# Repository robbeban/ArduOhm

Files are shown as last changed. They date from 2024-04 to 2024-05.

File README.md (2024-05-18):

# ArduOhm
Roberto De Colle ver. 0.2
22.4.2024

Ohmmeter with automatic scale with Arduino

Use a voltage divider with known R1 and unknown Rx as in the picture.

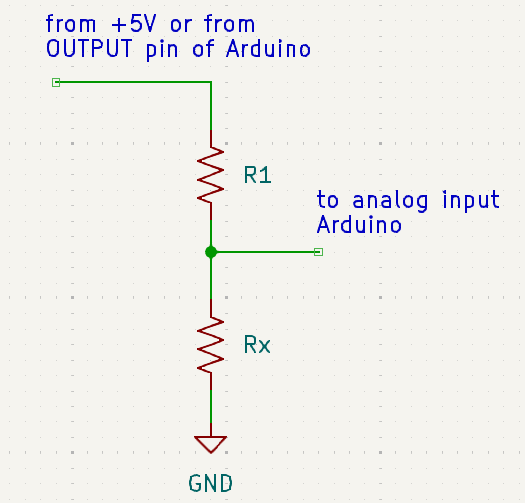
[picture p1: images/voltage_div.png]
<br>
Voltage on Rx is read from AnalogRead(A0) and converted in volt.

## Problem
With a fix R1 value (as 1K), the Rx value can be not accurate enough if Rx << R1 or Rx >> R1.
Therefore we need to change measurement scale changing the R1 value to be more similar to Rx value.<br>
## Solution
This can be made using 5 different R1 values and therefore 5 different measurement scale.

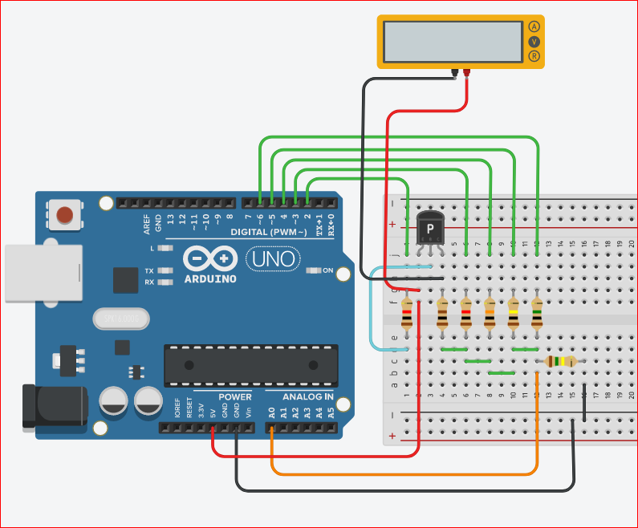
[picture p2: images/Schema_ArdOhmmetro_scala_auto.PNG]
<br>

In pic you see 5 different "R1" resistor, 100, 1K, 10K, 100K, 1M.
5 Output pins of Arduino put 5V on the right R1, but just one output at a time can be on +5V otherwise all R1 will be 
in parallel as one resistor.
This is achieved setting all output pin as input pin (equivalent R is great and therefore no resistor is connected to 5V) and then just one pin at a time is setted as output e brought to +5V.
This make an automatic scale to use the suitable value for R1.
## Another problem
By measuring little values of Rx, the right scale has a R1 = 100; with little value of R1+Rx the current provided from Arduino is too high (ca. 50 mA or more).
Therefore we use a PNP transistor to request just a few little current from pin.
In order of turning on the PNP transistor, we need to set output pin LOW instead of HIGH as for the other scales.

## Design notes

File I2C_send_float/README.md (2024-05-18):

# Prova per trasmettere dati float tra due Arduino collegati via I2C

Schema di collegamento<br>
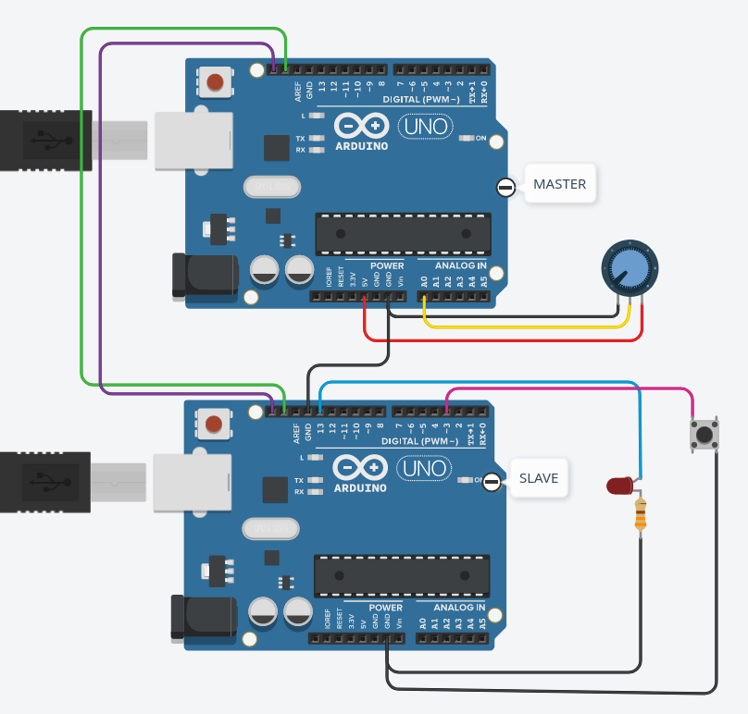
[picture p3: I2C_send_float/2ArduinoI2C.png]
<br>

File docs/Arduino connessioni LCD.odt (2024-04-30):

Connessione DISPLAYTECH 162B

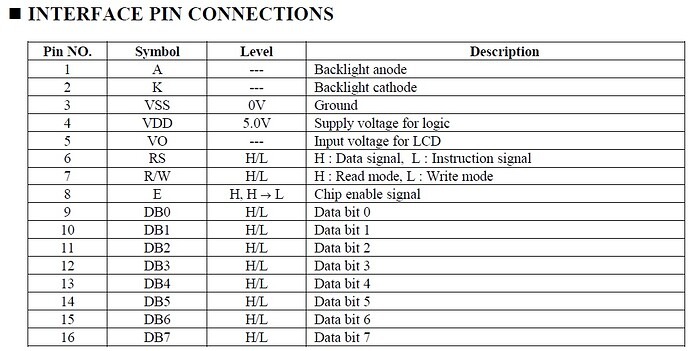
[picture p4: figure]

MANCA SCHEMA DI MONTAGGIO!!!!!!

Connessione DISPLAY 1602A

Pin. N. | Simbolo | Descrizione
1 | VSS | collegamento a terra
2 | VDD | alimentazione 5 volt
3 | V0 | regolazione del contrasto
4 | RS | register select: High=dati, Low=istruzioni
5 | R/W | High=Read; Low=Write
6 | E | Abilita (High) o disabilita (Low) l’ingresso di un byte
7 | D0 | data bus - bit 0
8 | D1 | data bus - bit 1
9 | D2 | data bus - bit 2
10 | D3 | data bus - bit 3
11 | D4 | data bus - bit 4
12 | D5 | data bus - bit 5
13 | D6 | data bus - bit 6
14 | D7 | data bus - bit 7
15 | BL-A | retroilluminazione (5 volt)
16 | BL-K | retroilluminazione (gnd)

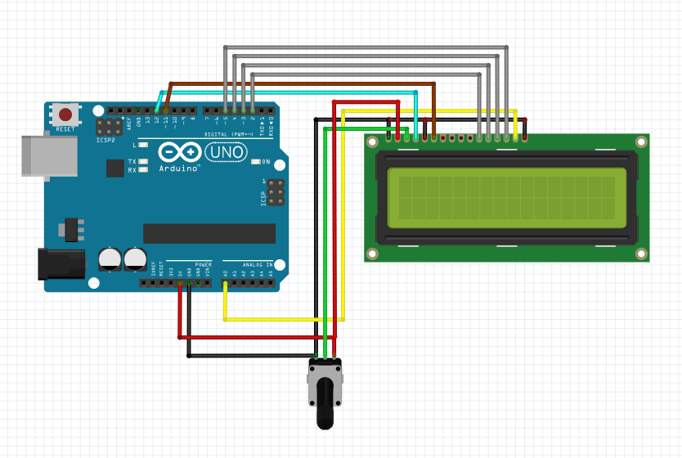
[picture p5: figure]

PIN ARDUINO | PIN LCD | | Pin ARDUINO alternativi
12 | RS | 4
11 | E | 6
5 | D7 | 14 | 10
4 | D6 | 13 | 9
3 | D5 | 12 | 8
2 | D4 | 11 | 7
GND | VSS | 1
+5V | VDD | 2
GND | R/W | 5
ALTRI PIN
POT1 | +5V
POT2 | V0 | 3
POT3 | GND
retro- | +5V | 15
iluminazione | GND | 16

Il display riceve, memorizza in un registro e visualizza il byte seguendo le istruzioni che gli vengono fornite attraverso i pin 4, 5 e 6. Piu’ in dettaglio:

- I pin da 1 a 3 sono utilizzati per alimentare il display e per regolare (mediante un potenziometro) il contrasto dei caratteri
- Il pin 4 (register select) è un selettore che, se dichiarato High predispone il registro del display a ricevere un byte mentre se dichiarato Low tiene il registro in attesa del prossimo evento.
- Il pin 5 stabilisce la modalità di utilizzo del registro. Se è LOW il registro è in ricezione (write) mentre se è HIGH il registro rende disponibile l’immagine del byte appena memorizzato. Se non si ha necessità di interrogare il byte presente nel registro conviene mantenere questo pin costantemente LOW e quindi collegato a terra.
- Il pin 6 abilita o disabilita l’ingresso e la visualizzazione del byte
- I pin da 7 a 14 rappresentano, come detto, la configurazione del byte da visualizzare
- I pin 15 e 16 sono utilizzati per illuminare il fondo del display. Devono essere collegati all’alimentazione da 5 volt ed alla massa o, eventualmente, ad un interruttore. Attenzione che a bordo scheda deve esserci la resistenza R8 (circa 100-330 ohm) per limitare la corrente. Possono anche ovviamente essere collegate ad una porta di Arduino e pilotate da programma (es. da una routine tipo luce crepuscolare).

Il display può lavorare in modalità 8 bit oppure in modalità 4 bit; se lavora in modalità 8 bit può visualizzare tutto il set di caratteri ascii (maiuscole, minuscole e caratteri speciali), ma richiede l’utilizzo di 10 porte mentre se lavora in modalità 4 bit utilizza solo 6 porte (4 per i dati, una per il selettore ed una per abilitare disabilitare la visualizzazione). Per mostrare un testo formato da numeri, caratteri maiuscoli o minuscoli e punteggiatura è sufficiente utilizzare la modalità a 4 bit.

Per provare tutte le funzionalità “fisiche” del display aggiungeremo anche un potenziometro collegato al pin 3 in modo da poter regolare il contrasto.

Verificare di poter collegare una semplice R da 330 ohm tra V0 e GND per regolare il contrasto!

E se si può collegare una semplice R da 6,8 Kohm tra pin 15 e +5V !!

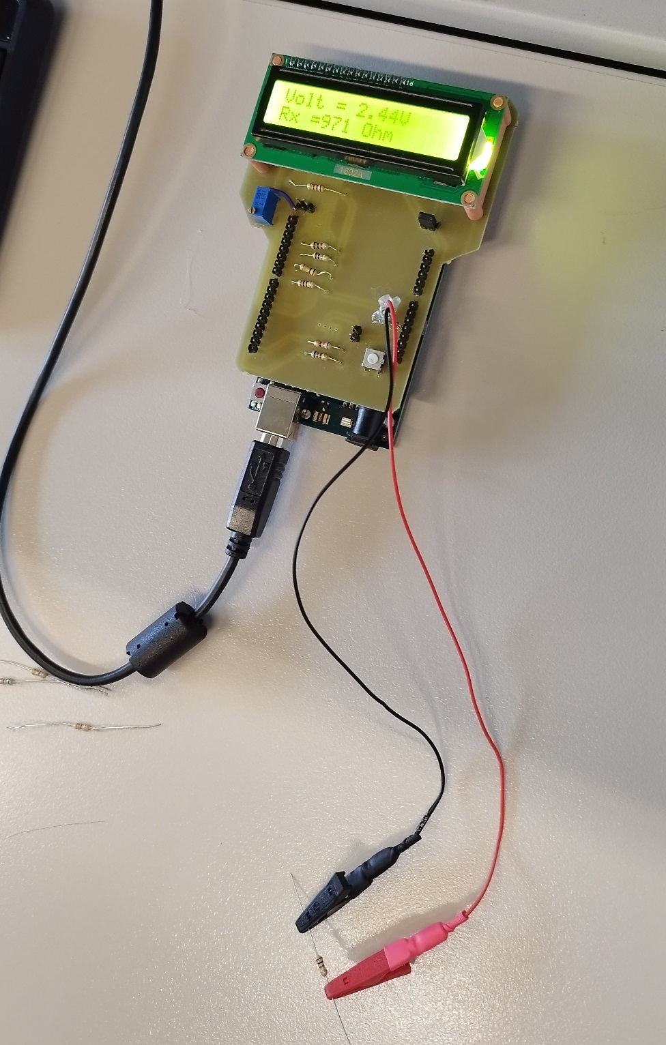
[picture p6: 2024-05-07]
images/Arduohmmetro2.jpg

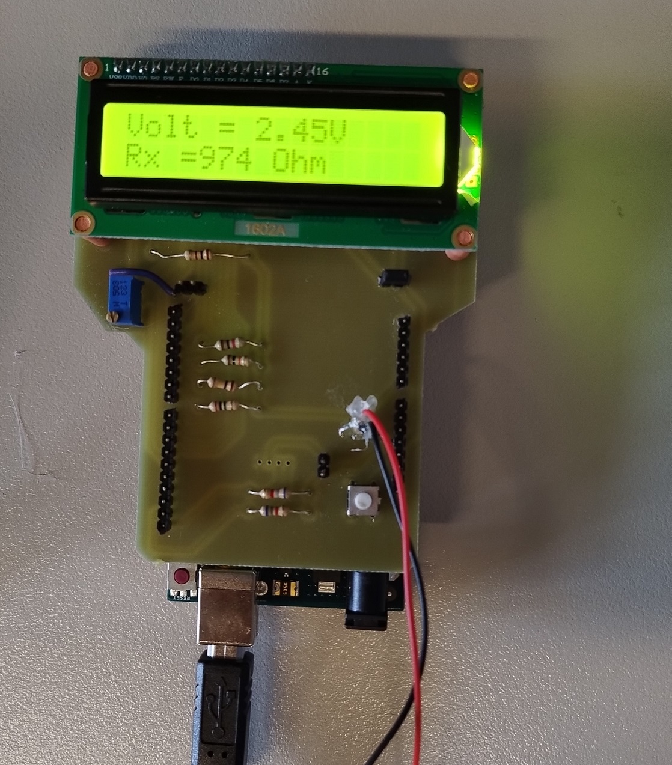
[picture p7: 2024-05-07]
images/Arduohmmetro1.jpg

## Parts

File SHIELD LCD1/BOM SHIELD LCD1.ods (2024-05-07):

H:\Documents\Documenti_scuola\Documenti_2023-2024\Didattica\2EL\KICAD\SHIELD LCD1\SHIELD LCD1.kicad_sch
02/05/2024 10:40:01
Eeschema 7.0.7
C:\Program Files\KiCad\7.0\bin\scripting\plugins/bom_csv_grouped_by_value.py
26
LISTA MATERIALI BOM
Qty | Reference(s) | Value | LibPart | Footprint
2 | J1, J4 | Conn_01x08 | Connector_Generic:Conn_01x08 | Connector_PinHeader_2.54mm:PinHeader_1x08_P2.54mm_Vertical
1 | J2 | Conn_01x10 | Connector_Generic:Conn_01x10 | Connector_PinHeader_2.54mm:PinHeader_1x10_P2.54mm_Vertical
1 | J3 | Conn_01x06 | Connector_Generic:Conn_01x06 | Connector_PinHeader_2.54mm:PinHeader_1x06_P2.54mm_Vertical
1 | J5 | RX | Connector_Generic:Conn_01x02 | Connector_PinHeader_2.54mm:PinHeader_1x02_P2.54mm_Vertical
1 | J6 | Conn_01x16 | Connector_Generic:Conn_01x16 | Connector_PinHeader_2.54mm:PinHeader_1x16_P2.54mm_Vertical
1 | J7 | Con2 | Connector_Generic:Conn_01x02 | Connector_PinHeader_2.54mm:PinHeader_1x02_P2.54mm_Vertical
1 | J8 | I2C | Connector_Generic:Conn_01x04 | Connector:NS-Tech_Grove_1x04_P2mm_Vertical
1 | JP1 | J5V | Jumper:Jumper_2_Open | TestPoint:TestPoint_2Pads_Pitch2.54mm_Drill0.8mm
1 | JP2 | BACKLIGHT | Jumper:Jumper_2_Open | TestPoint:TestPoint_2Pads_Pitch2.54mm_Drill0.8mm
1 | Q1 | BC556 | Transistor_BJT:BC556 | Package_TO_SOT_THT:TO-92_Inline_Wide
2 | R1, R3 | 1K | Device:R | Resistor_THT:R_Axial_DIN0309_L9.0mm_D3.2mm_P12.70mm_Horizontal
1 | R2 | 100 | Device:R | Resistor_THT:R_Axial_DIN0411_L9.9mm_D3.6mm_P20.32mm_Horizontal
1 | R4 | 10K | Device:R | Resistor_THT:R_Axial_DIN0309_L9.0mm_D3.2mm_P12.70mm_Horizontal
1 | R5 | 100K | Device:R | Resistor_THT:R_Axial_DIN0309_L9.0mm_D3.2mm_P12.70mm_Horizontal
1 | R6 | 1M | Device:R | Resistor_THT:R_Axial_DIN0309_L9.0mm_D3.2mm_P12.70mm_Horizontal
2 | R7, R8 | 6K8 | Device:R | Resistor_THT:R_Axial_DIN0309_L9.0mm_D3.2mm_P12.70mm_Horizontal
1 | RV1 | 50K | Device:R_Potentiometer_Trim | Potentiometer_THT:Potentiometer_Bourns_3296X_Horizontal
1 | SW1 | RESET | Switch:SW_MEC_5E | 00_MATTEI:SW_PUSH_6mm_H4.3mm

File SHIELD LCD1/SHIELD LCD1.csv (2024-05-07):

Source: | H:\Documents\Documenti_scuola\Documenti_2023-2024\Didattica\2EL\KICAD\SHIELD LCD1\SHIELD LCD1.kicad_sch
Date: | 02/05/2024 10:40:01
Tool: | Eeschema 7.0.7
Generator: | C:\Program Files\KiCad\7.0\bin\scripting\plugins/bom_csv_grouped_by_value.py
Component Count: | 26
Collated Components:
Item | Qty | Reference(s) | Value | LibPart | Footprint | Datasheet | DNP
1 | 1 | DS1 | WC1602A | Display_Character:WC1602A | Display:WC1602A | http://www.wincomlcd.com/pdf/WC1602A-SFYLYHTC06.pdf
2 | 4 | H1, H2, H3, H4 | MountingHole | Mechanical:MountingHole | MountingHole:MountingHole_2.5mm | ~
3 | 2 | J1, J4 | Conn_01x08 | Connector_Generic:Conn_01x08 | Connector_PinHeader_2.54mm:PinHeader_1x08_P2.54mm_Vertical | ~
4 | 1 | J2 | Conn_01x10 | Connector_Generic:Conn_01x10 | Connector_PinHeader_2.54mm:PinHeader_1x10_P2.54mm_Vertical | ~
5 | 1 | J3 | Conn_01x06 | Connector_Generic:Conn_01x06 | Connector_PinHeader_2.54mm:PinHeader_1x06_P2.54mm_Vertical | ~
6 | 1 | J5 | RX | Connector_Generic:Conn_01x02 | Connector_PinHeader_2.54mm:PinHeader_1x02_P2.54mm_Vertical | ~
7 | 1 | J6 | Conn_01x16 | Connector_Generic:Conn_01x16 | Connector_PinHeader_2.54mm:PinHeader_1x16_P2.54mm_Vertical | ~
8 | 1 | J7 | Con2 | Connector_Generic:Conn_01x02 | Connector_PinHeader_2.54mm:PinHeader_1x02_P2.54mm_Vertical | ~
9 | 1 | J8 | I2C | Connector_Generic:Conn_01x04 | Connector:NS-Tech_Grove_1x04_P2mm_Vertical | ~
10 | 1 | JP1 | J5V | Jumper:Jumper_2_Open | TestPoint:TestPoint_2Pads_Pitch2.54mm_Drill0.8mm | ~
11 | 1 | JP2 | BACKLIGHT | Jumper:Jumper_2_Open | TestPoint:TestPoint_2Pads_Pitch2.54mm_Drill0.8mm | ~
12 | 1 | Q1 | BC556 | Transistor_BJT:BC556 | Package_TO_SOT_THT:TO-92_Inline_Wide | https://www.onsemi.com/pub/Collateral/BC556BTA-D.pdf
13 | 2 | R1, R3 | 1K | Device:R | Resistor_THT:R_Axial_DIN0309_L9.0mm_D3.2mm_P12.70mm_Horizontal | ~
14 | 1 | R2 | 100 | Device:R | Resistor_THT:R_Axial_DIN0411_L9.9mm_D3.6mm_P20.32mm_Horizontal | ~
15 | 1 | R4 | 10K | Device:R | Resistor_THT:R_Axial_DIN0309_L9.0mm_D3.2mm_P12.70mm_Horizontal | ~
16 | 1 | R5 | 100K | Device:R | Resistor_THT:R_Axial_DIN0309_L9.0mm_D3.2mm_P12.70mm_Horizontal | ~
17 | 1 | R6 | 1M | Device:R | Resistor_THT:R_Axial_DIN0309_L9.0mm_D3.2mm_P12.70mm_Horizontal | ~
18 | 2 | R7, R8 | 6K8 | Device:R | Resistor_THT:R_Axial_DIN0309_L9.0mm_D3.2mm_P12.70mm_Horizontal | ~
19 | 1 | RV1 | 50K | Device:R_Potentiometer_Trim | Potentiometer_THT:Potentiometer_Bourns_3296X_Horizontal | ~
20 | 1 | SW1 | RESET | Switch:SW_MEC_5E | 00_MATTEI:SW_PUSH_6mm_H4.3mm | http://www.apem.com/int/index.php?controller=attachment&id_attachment=1371

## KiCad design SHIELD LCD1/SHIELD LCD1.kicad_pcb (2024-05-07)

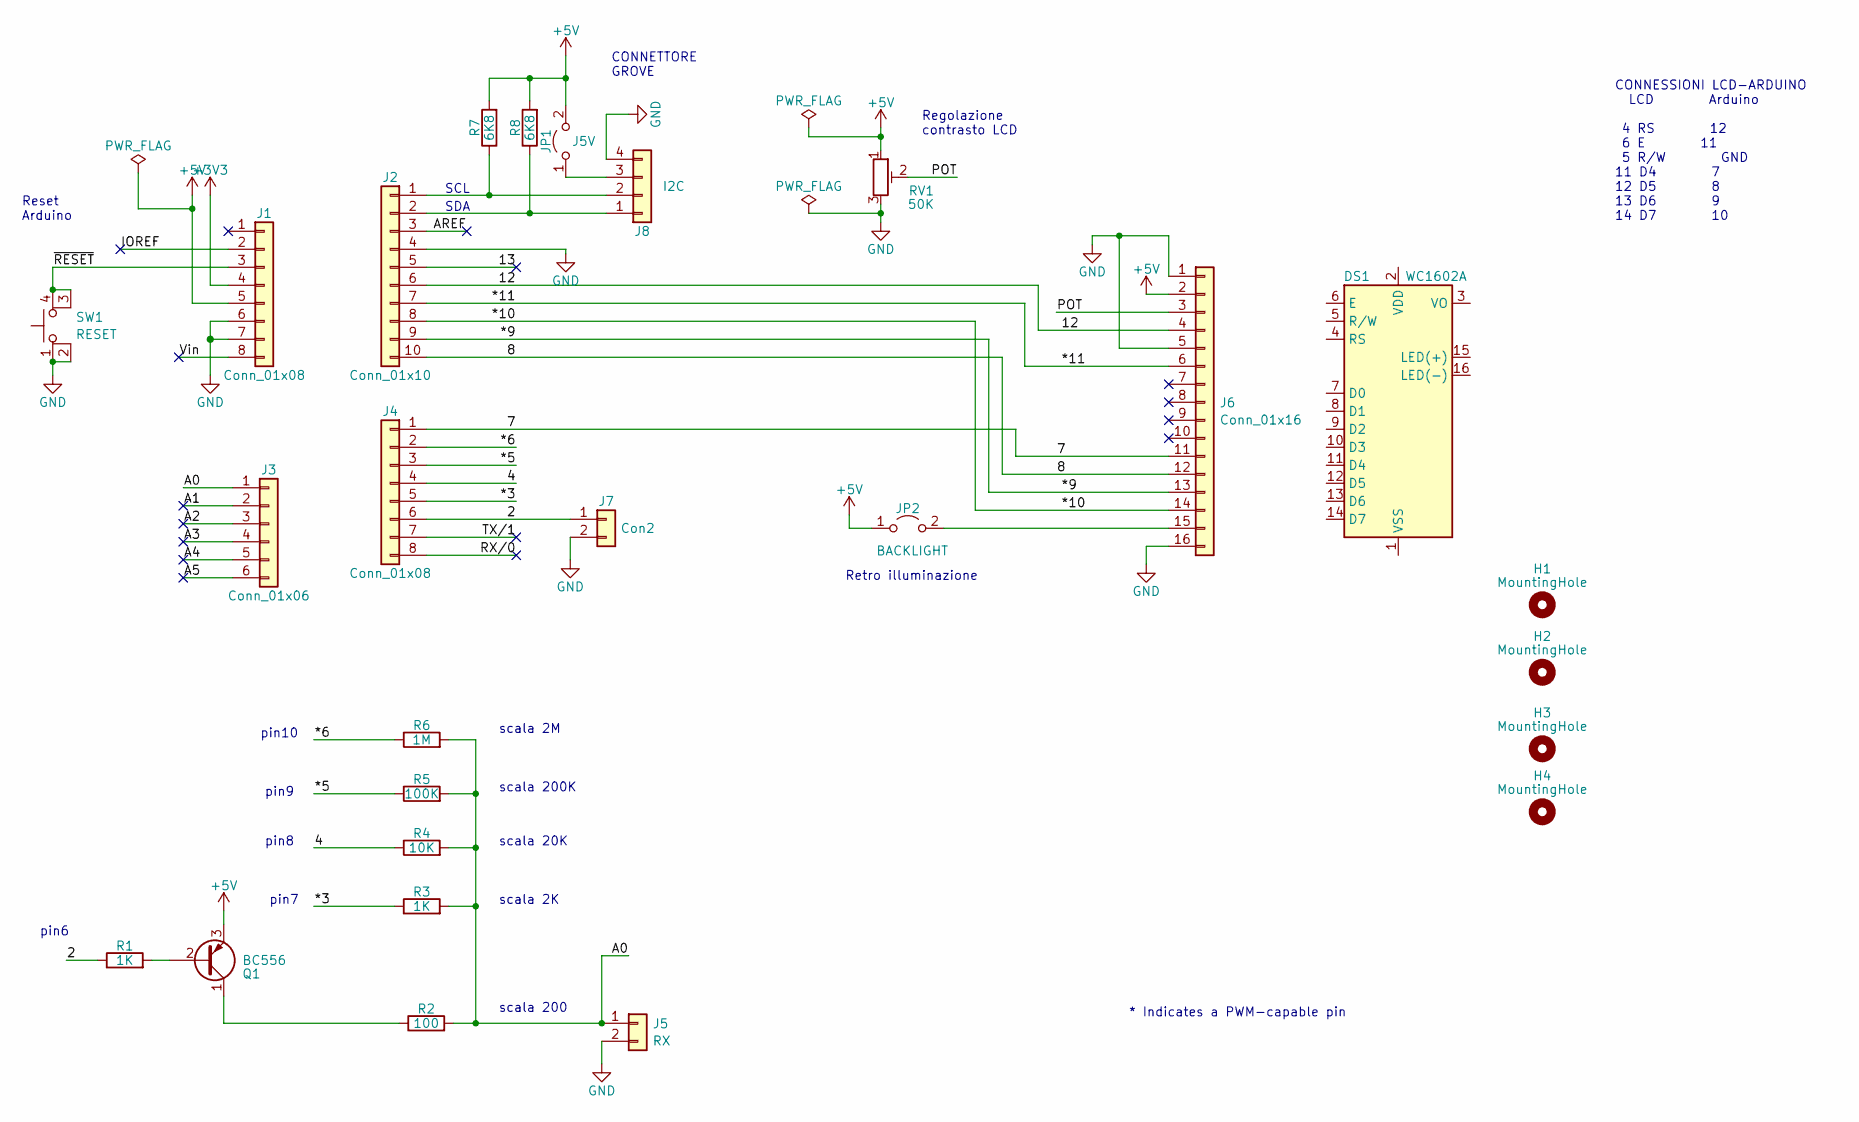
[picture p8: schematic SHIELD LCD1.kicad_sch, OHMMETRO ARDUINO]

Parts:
DS1: WC1602A
H1, H2, H3, H4: MountingHole; MountingHole_2.5mm
J1, J4: Conn_01x08; PinHeader_1x08_P2.54mm_Vertical
J2: Conn_01x10; PinHeader_1x10_P2.54mm_Vertical
J3: Conn_01x06; PinHeader_1x06_P2.54mm_Vertical
J5: RX; PinHeader_1x02_P2.54mm_Vertical
J6: Conn_01x16; PinHeader_1x16_P2.54mm_Vertical
J7: Con2; PinHeader_1x02_P2.54mm_Vertical
J8: I2C; NS-Tech_Grove_1x04_P2mm_Vertical
JP1: J5V; TestPoint_2Pads_Pitch2.54mm_Drill0.8mm
JP2: BACKLIGHT; TestPoint_2Pads_Pitch2.54mm_Drill0.8mm
Q1: BC556; TO-92_Inline_Wide
R1, R3: 1K; R_Axial_DIN0309_L9.0mm_D3.2mm_P12.70mm_Horizontal
R2: 100; R_Axial_DIN0411_L9.9mm_D3.6mm_P20.32mm_Horizontal
R4: 10K; R_Axial_DIN0309_L9.0mm_D3.2mm_P12.70mm_Horizontal
R5: 100K; R_Axial_DIN0309_L9.0mm_D3.2mm_P12.70mm_Horizontal
R6: 1M; R_Axial_DIN0309_L9.0mm_D3.2mm_P12.70mm_Horizontal
R7, R8: 6K8; R_Axial_DIN0309_L9.0mm_D3.2mm_P12.70mm_Horizontal
RV1: 50K; Potentiometer_Bourns_3296X_Horizontal
SW1: RESET; SW_PUSH_6mm_H4.3mm

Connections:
+3V3: J1.4
+5V: J1.5, J6.2, JP1.2 (B), JP2.1 (A), Q1.3 (E), R7.2, R8.2, RV1.1
/2: J4.6, J7.1, R1.1
/4: J4.4, R4.1
/7: J4.1, J6.11
/8: J2.10, J6.12
/12: J2.6, J6.4
/13: J2.5
/*3: J4.5, R3.1
/*5: J4.3, R5.1
/*6: J4.2, R6.1
/*9: J2.9, J6.13
/*10: J2.8, J6.14
/*11: J2.7, J6.6
/A0: J3.1, J5.1, R2.2, R3.2, R4.2, R5.2, R6.2
/A1: J3.2
/A2: J3.3
/A3: J3.4
/A4: J3.5
/A5: J3.6
/AREF: J2.3
/IOREF: J1.2
/POT: J6.3, RV1.2
/RX/0: J4.8
/TX/1: J4.7
/Vin: J1.8
/~RESET: J1.3, SW1.3 (K), SW1.4 (A)
GND: J1.6, J1.7, J2.4, J5.2, J6.1, J6.5, J6.16, J7.2, J8.4, RV1.3, SW1.1, SW1.2
unnamed: J2.1, J8.2, R7.1
unnamed: J2.2, J8.1, R8.1
unnamed: J6.15, JP2.2 (B)
unnamed: J8.3, JP1.1 (A)
unnamed: Q1.2 (B), R1.2
unnamed: Q1.1 (C), R2.1

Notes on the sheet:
SCL
Reset Arduino
SDA
scala 20K
pin6
scala 200K
Retro illuminazione
scala 200
pin7
scala 2K
* Indicates a PWM-capable pin
CONNESSIONI LCD-ARDUINO LCD Arduino 4 RS 12 6 E 11 5 R/W GND 11 D4 7 12 D5 8 13 D6 9 14 D7 10
pin10
scala 2M
CONNETTORE GROVE
pin9
Regolazione contrasto LCD
pin8

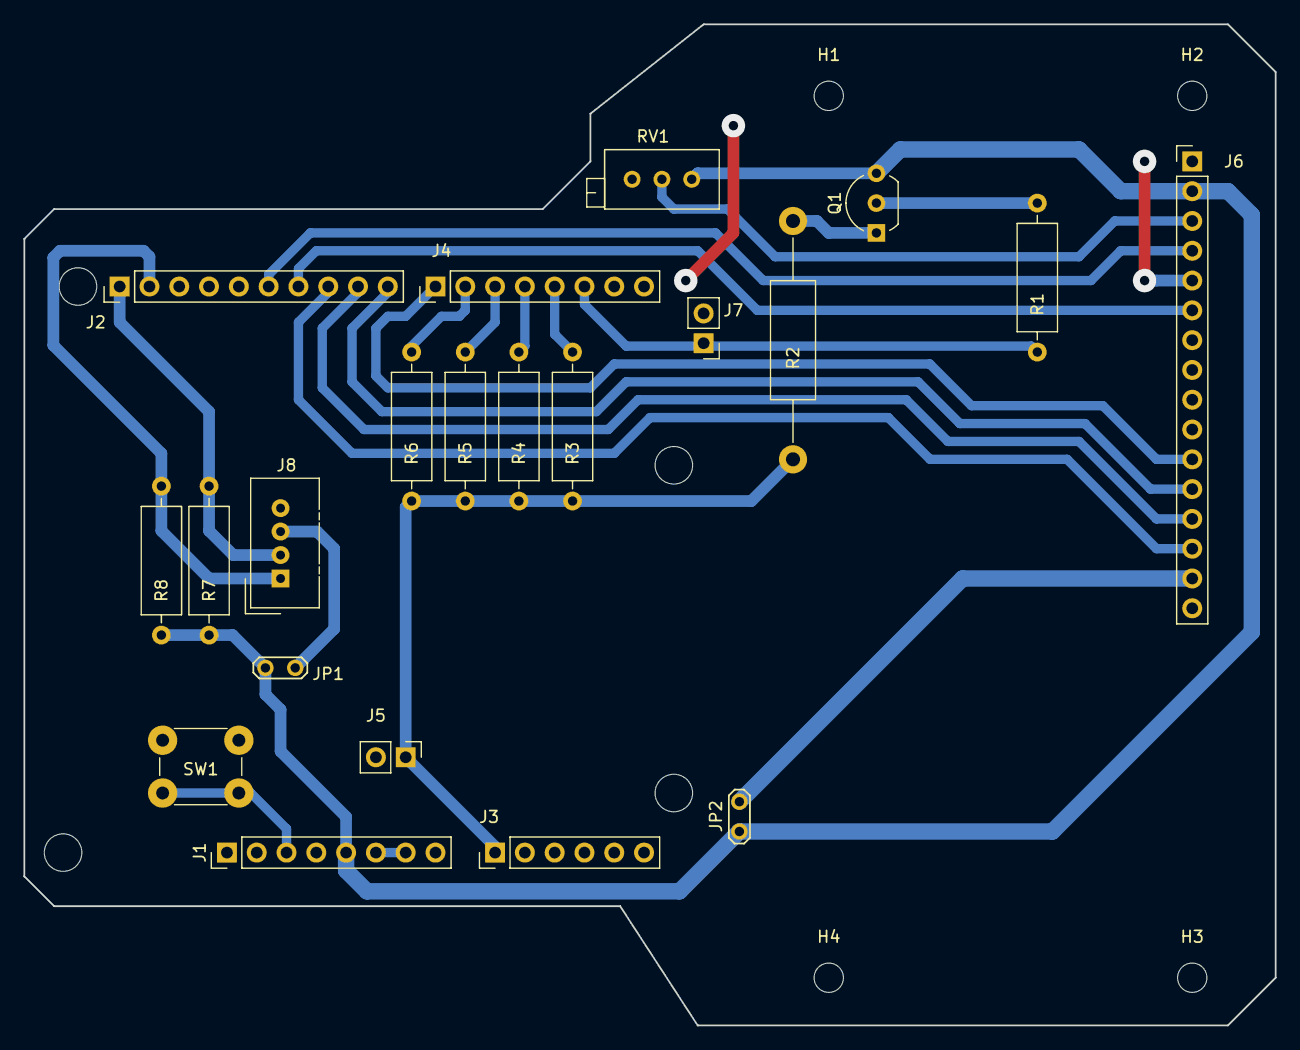
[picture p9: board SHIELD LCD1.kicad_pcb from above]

Board: 2 copper layers, 106.7 x 85.3 mm, 29 parts (0 on the bottom side), 22 nets.

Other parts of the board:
MH1, MH2, MH3, MH4: MountingHole_3.2mm

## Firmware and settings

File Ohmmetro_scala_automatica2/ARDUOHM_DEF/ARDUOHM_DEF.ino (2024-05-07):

/*Misura una resistenza Rx collegata come partitore ad una resistenza R1.
La Vin = +5V da Arduino, le 2 R sono in serie, Rx va a GND. In mezzo alle R c'è il collegamento
all' ingresso analogico.
Attenzione: per valori bassi (<20 ohm) o molto alti (> 100K) la misura non è precisa,
manca il cambio scala dell'ohmmetro.
Roberto De Colle 7.5.24 Ver. 0.99 */

#include <LiquidCrystal.h>
//LiquidCrystal(rs, enable, d4, d5, d6, d7);
//LiquidCrystal lcd(12, 11, 2, 3, 4, 5);  //valori "normali"
LiquidCrystal lcd(12, 11, 7, 8, 9, 10);  //collegamenti per lo SHIELD LCD1

int val;         //valore letto 0..1023
float Rx, volt;  //Rx da misurare, volt calcolati sulla Rx
//int pin[5] = { 6, 5, 4, 3, 2 };                                 //pin dove collegare le R1 da 1M, 100K, 10K, 1K, 100
int pin[5] = { 10, 9, 8, 7, 6 };
float R1[5] = { 1000000.0, 100000.0, 10000.0, 1000.0, 100.0 };  //valori di R1
bool misura_ok = false;
int scala = 4;            //partiamo dalla scala più bassa


void setup() {
  lcd.begin(16, 2);  //inizializza display a 16 car. e 2 righe
  lcd.clear();       //pulisce lo schermo
  lcd.print("OHMMETRO ARDUINO");
  delay(3000);
  Serial.begin(9600);
}

void loop() {
  staccatutto();                //stacca tutti i pin
  pinMode(pin[scala], OUTPUT);  //attivo il pin giusto
  if (scala == 4)
    digitalWrite(pin[scala], LOW);  //metto basso il pin del PNP
  else
    digitalWrite(pin[scala], HIGH);  //metto alto il pin della R1
  val = analogRead(A0);
  delay(100);
  if (val > 693) {               //se il val letto non è buono...
    if (scala > 0)                //se la scala non è la massima..
      scala--;                    //.. cambia scala
    else {                        //altrimenti fai i calcoli
      calcola(R1[scala]);         
      stampa();
      debug();
    }
    else {
      calcola(R1[scala]);
      stampa();
      debug();
    }
  }
}

void calcola(float R) {
  volt = 5.0 / 1023 * val;       //calcola i volt su Rx
  Rx = volt * R / (5.0 - volt);  //calcola Rx
}
//stampa su LCD i valori di Volt e Rx calcolati
void stampa() {
  lcd.clear();
  lcd.print("Volt= ");
  lcd.print(volt);
  lcd.print(" V");
  lcd.setCursor(0, 1);         //passiamo alla seconda riga
  if (val >= 1020)             //se la lettura è troppo grande
    lcd.print("Inserire Rx");  //la Rx non è inserita
  else {
    lcd.print("Rx = ");
    if (Rx >= 10)           //se la Rx è grande
      lcd.print(long(Rx));  //stampa valore senza virgola, NON int ma long!
    else
      lcd.print(Rx);    //se la Rx è piccola
    lcd.print(" ohm");  //stampa valore con virgola
  }
}

void staccatutto() {  //mette tutti i pin R1 INPUT
  for (int i = 0; i <= 4; i++) {
    pinMode(pin[i], INPUT);
  }
}

void debug() {
  Serial.print("scala = ");
  Serial.println(scala);
  Serial.print("R1 = ");
  Serial.println(R1[scala]);
  Serial.print("val = ");
  Serial.println(val);
  Serial.print("Rx = ");
  Serial.println(Rx);
}

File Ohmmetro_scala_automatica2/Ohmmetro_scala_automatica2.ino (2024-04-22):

//Roberto De Colle
//ver. 0.2
//22.4.2024

int val;                                                     //valore letto
float Rx, tensione;                                          //Rx resistenza da misurare, tensione calcolata
float R1 = { 100.0, 1000.0, 10000.0, 100000.0, 1000000.0 };  //valori di R1
int pin = { 1, 2, 3, 4, 5 };                                 //pin dove sono collegati le R1
bool misura_ok = FALSE;

void setup() {
  Serial.begin(9600);
  //imposta LCD
  for (int i; i < 5; i++) {  //stacca tutte le R1
    pinMode(pin[i], INPUT);
  }
  scala = 0;
}

void loop() {
  if (!misura_ok) {
    for (int k; k < 5; k++)  //stacca tutte le R1
      pinMode(pin[k], INPUT);

    pinMode(pin[scala], OUTPUT);  //attiva la R1 della scala attuale
    if (scala == 0)
      digitalWrite(pin[scala], LOW);  //attiva il PNP
    else
      digitalWrite(pin[scala], HIGH);  //manda 5V sulla R1

    val = analogRead(A0);
    if (val <= 683) {                //se il valore letto è buono..
      Rx = Calcola(val, R1[scala]);  //calcola il valore di Rx con la R1 della scala corretta
      Stampa();
      misura_ok = TRUE;
    } else {
      scala++;
    }
  }
}

float Calcola(int v, float R1) {
  tensione = 5 * val / 1023;
  return tensione * R1 / (5 - R1);
}

void Stampa() {
  lcd.clear();
  lcd.print("tensione= ");
  Serial.print("tensione= ");
  lcd.print(tensione);
  Serial.print(tensione);
  lcd.print(" V");
  Serial.println(" V");
  lcd.setCursor(1, 0);
  if (tensione < 5.0) {  //se la tensione non è 5 V
    lcd.print("Rx= ");
    Serial.print("Rx= ");
    if (Rx < 10.) {
      lcd.print(Rx);  //per resistenze piccole (<10) stampa il valore con la virgola
      Serial.print(Rx);
    } else {
      lcd.print(int(Rx));  //per resistenze grandi (>10) stampa il valore senza virgola
    }
    lcd.print(" Ohm");
    Serial.println(" Ohm");
  } else {  //se invece la tensione è al massimo..
    lcd.println("Inserire Resistenza");
    Serial.println("Inserire Resistenza");
  }
}

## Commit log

2024-04-22 Add some pics
    voltage divider
2024-04-30 Add files via upload
    Ohmmetro2 prova scala automatica come provato a lezione il 30/4/24
    parte dalla scala 0 che corrisponde a R1=1M
2024-04-30 Add files via upload
    Documento Connessioni Arduino LCD
2024-04-30 Add files via upload
    Attenzione: i collegamenti sono corretti rispetto ai pin dell'LCD, come da file Kicad
2024-05-07 Addd Arduino sketch definitivo
    ancora da provare V. 0.99
2024-05-07 Add file
    Kicad file shield Arduohmmetro con LCD
    Attenzione: per Kicad vers. 7
    [BOM SHIELD LCD1.ods, SHIELD LCD1.csv, SHIELD LCD1.kicad_pcb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]
2024-05-18 Add files via upload
    Sketch arduino di prova per trasmettere dati float via I2C da un Arduino master ad un altro slave
